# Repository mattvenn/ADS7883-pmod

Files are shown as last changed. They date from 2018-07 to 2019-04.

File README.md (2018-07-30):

# PMOD 2 x ADS7883 ADC

the ADS7883 is a 12 bit, serial ADC. It can sample up to 3MHz, and can be supplied up to 5v.

It needs 3 pins to operate: clk, select and data.

Supply can be 3.3v from the PMOD (limits maximum range of ADC to 3.3v), or 5v with a 
precision regulator and an external supply between 5.5v and 16v.

Use the ext/pmod jumper to select the source.

schematic

board

# Gerbers

## [fab-ADS7883-pmod-2018-07-02.zip](fab-ADS7883-pmod-2018-07-02.zip)

The silkscreen has an error on the 2 inputs. The 0v and ADC inputs are reversed. Attach 0v to ADC and ADC input to 0v.

## [fab-ADS7883-pmod-2018-07-30.zip](fab-ADS7883-pmod-2018-07-30.zip)

Fixes the reversed input labels.

# BOM

If you are using PMOD 3.3v for supply, you don't need C7, U1, C5.

LED D1 and R2 are optional for indicating PSU is good.

C1 to C4 are bypass caps and will help to improve noise performance if added.

* ADC1 and 2: ADS7883 http://es.farnell.com/texas-instruments/ads7883sbdbvt/adc-sar-12bit-3msps-6sot23/dp/2082426
* U1: ref5050 http://es.farnell.com/texas-instruments/ref5050aidg4/ref-de-tensi-n-serie-5v-soic-8/dp/1439628

# Verilog Core

[icestick/adc.v](adc.v) is tested Verilog for the ADC.

A working demo for the icestick is provided in the [icestick](icestick) directory. This reads ADC1 and shows top 5 bits on the icestick's LEDs.

To synthesise and program an attached icestick using the Icestorm tools:

    make prog

To simulate using iverilog and launch gtkwave to view the waveforms:

    make debug-adc

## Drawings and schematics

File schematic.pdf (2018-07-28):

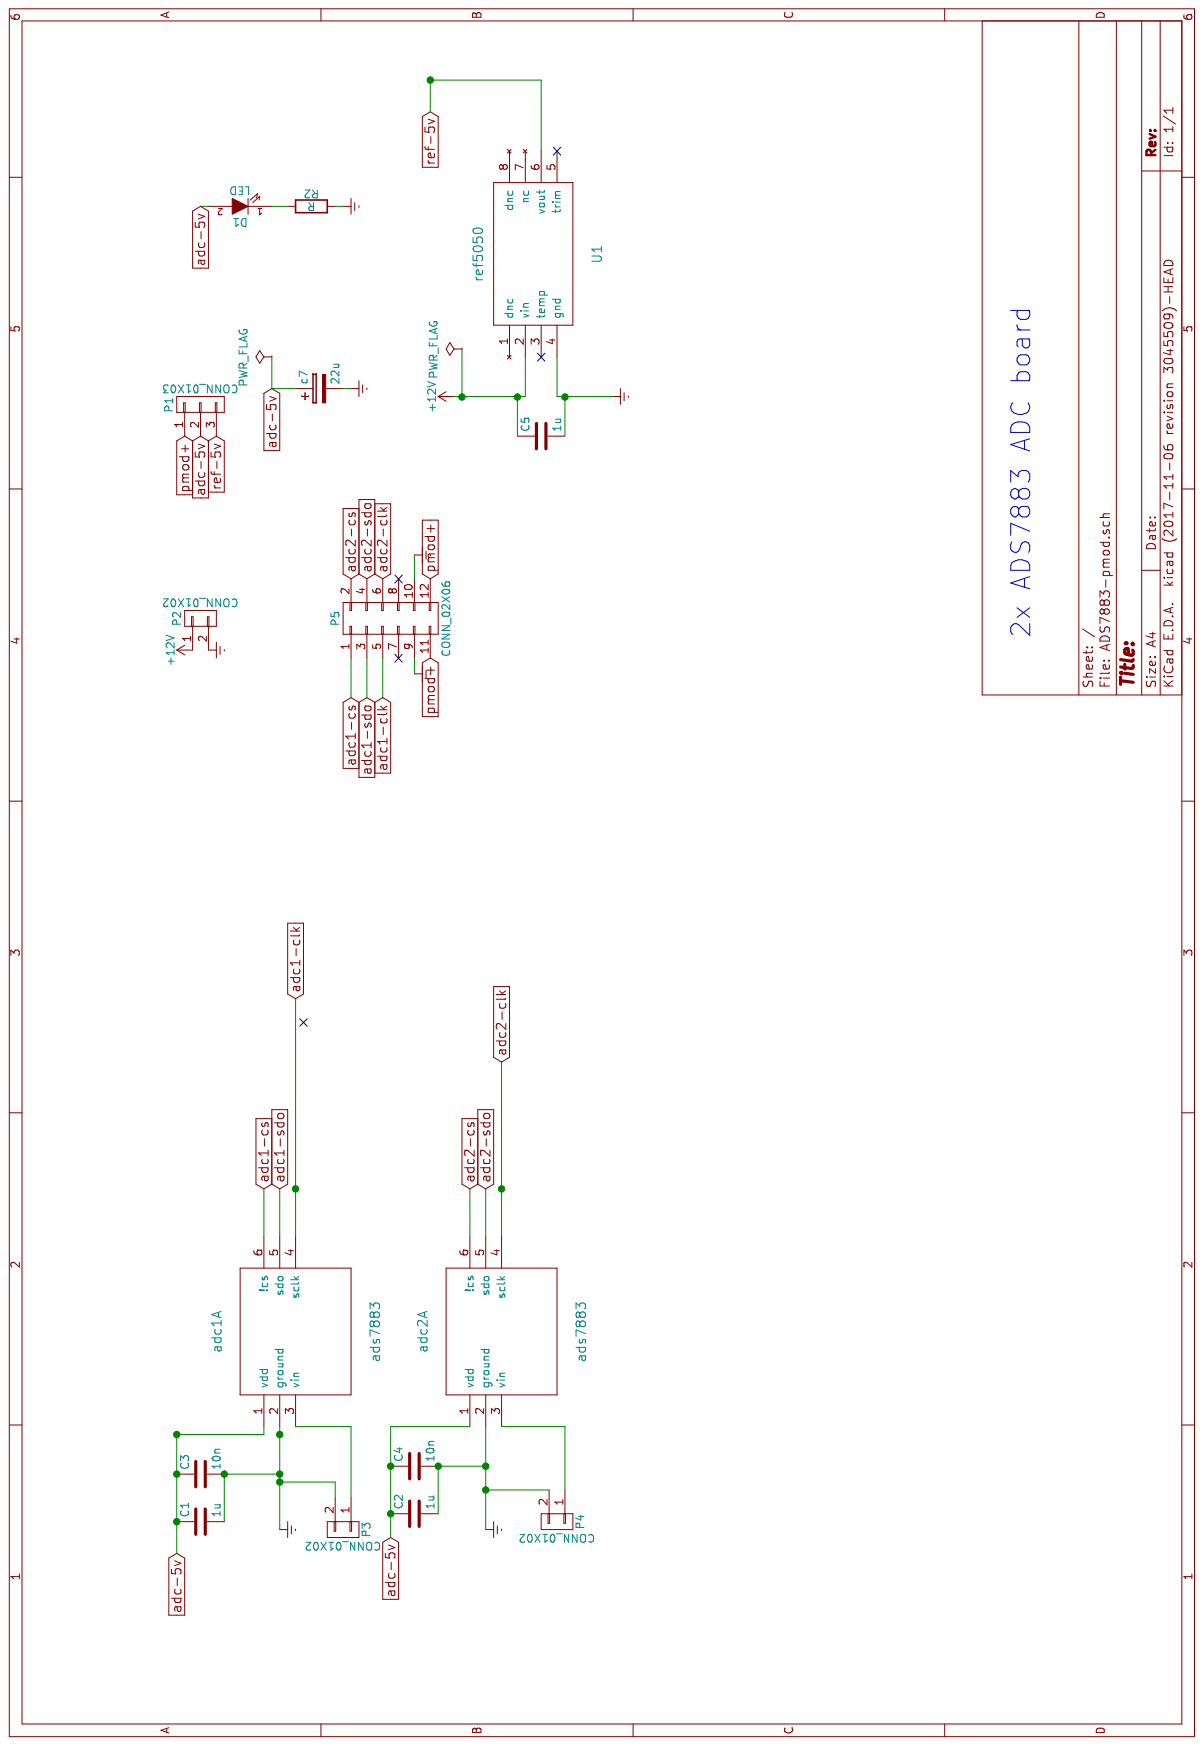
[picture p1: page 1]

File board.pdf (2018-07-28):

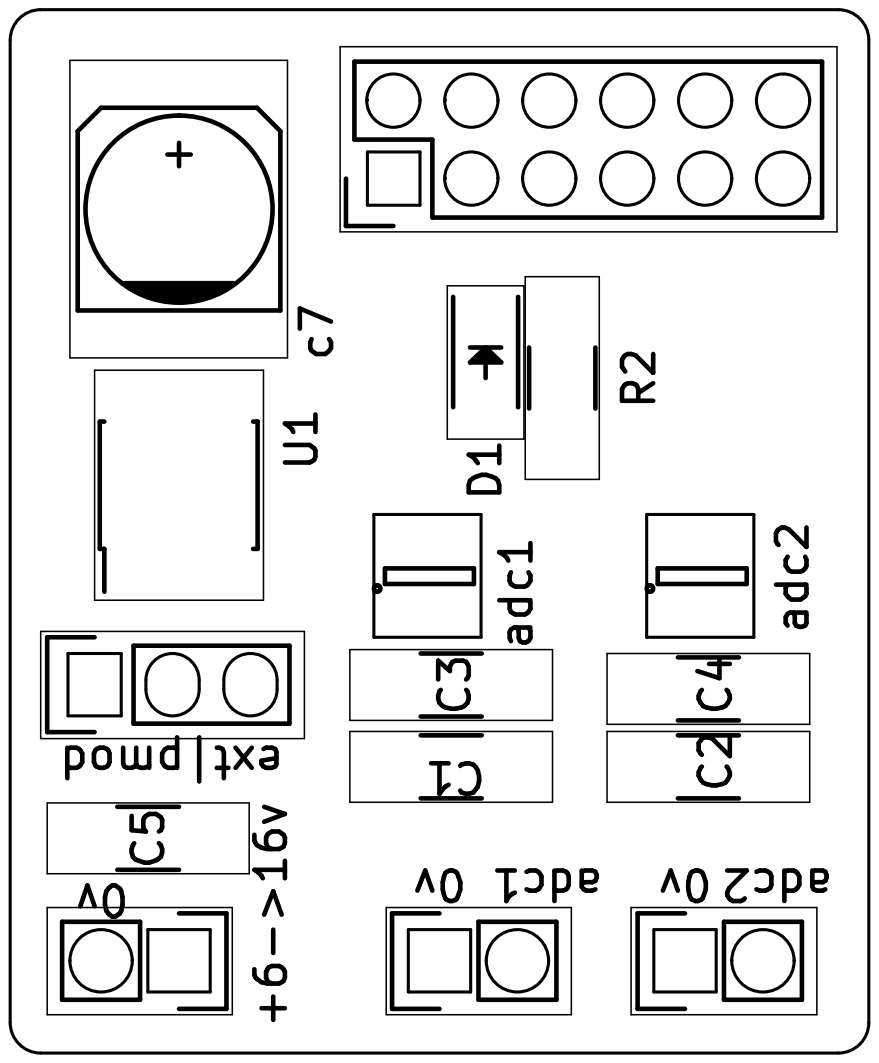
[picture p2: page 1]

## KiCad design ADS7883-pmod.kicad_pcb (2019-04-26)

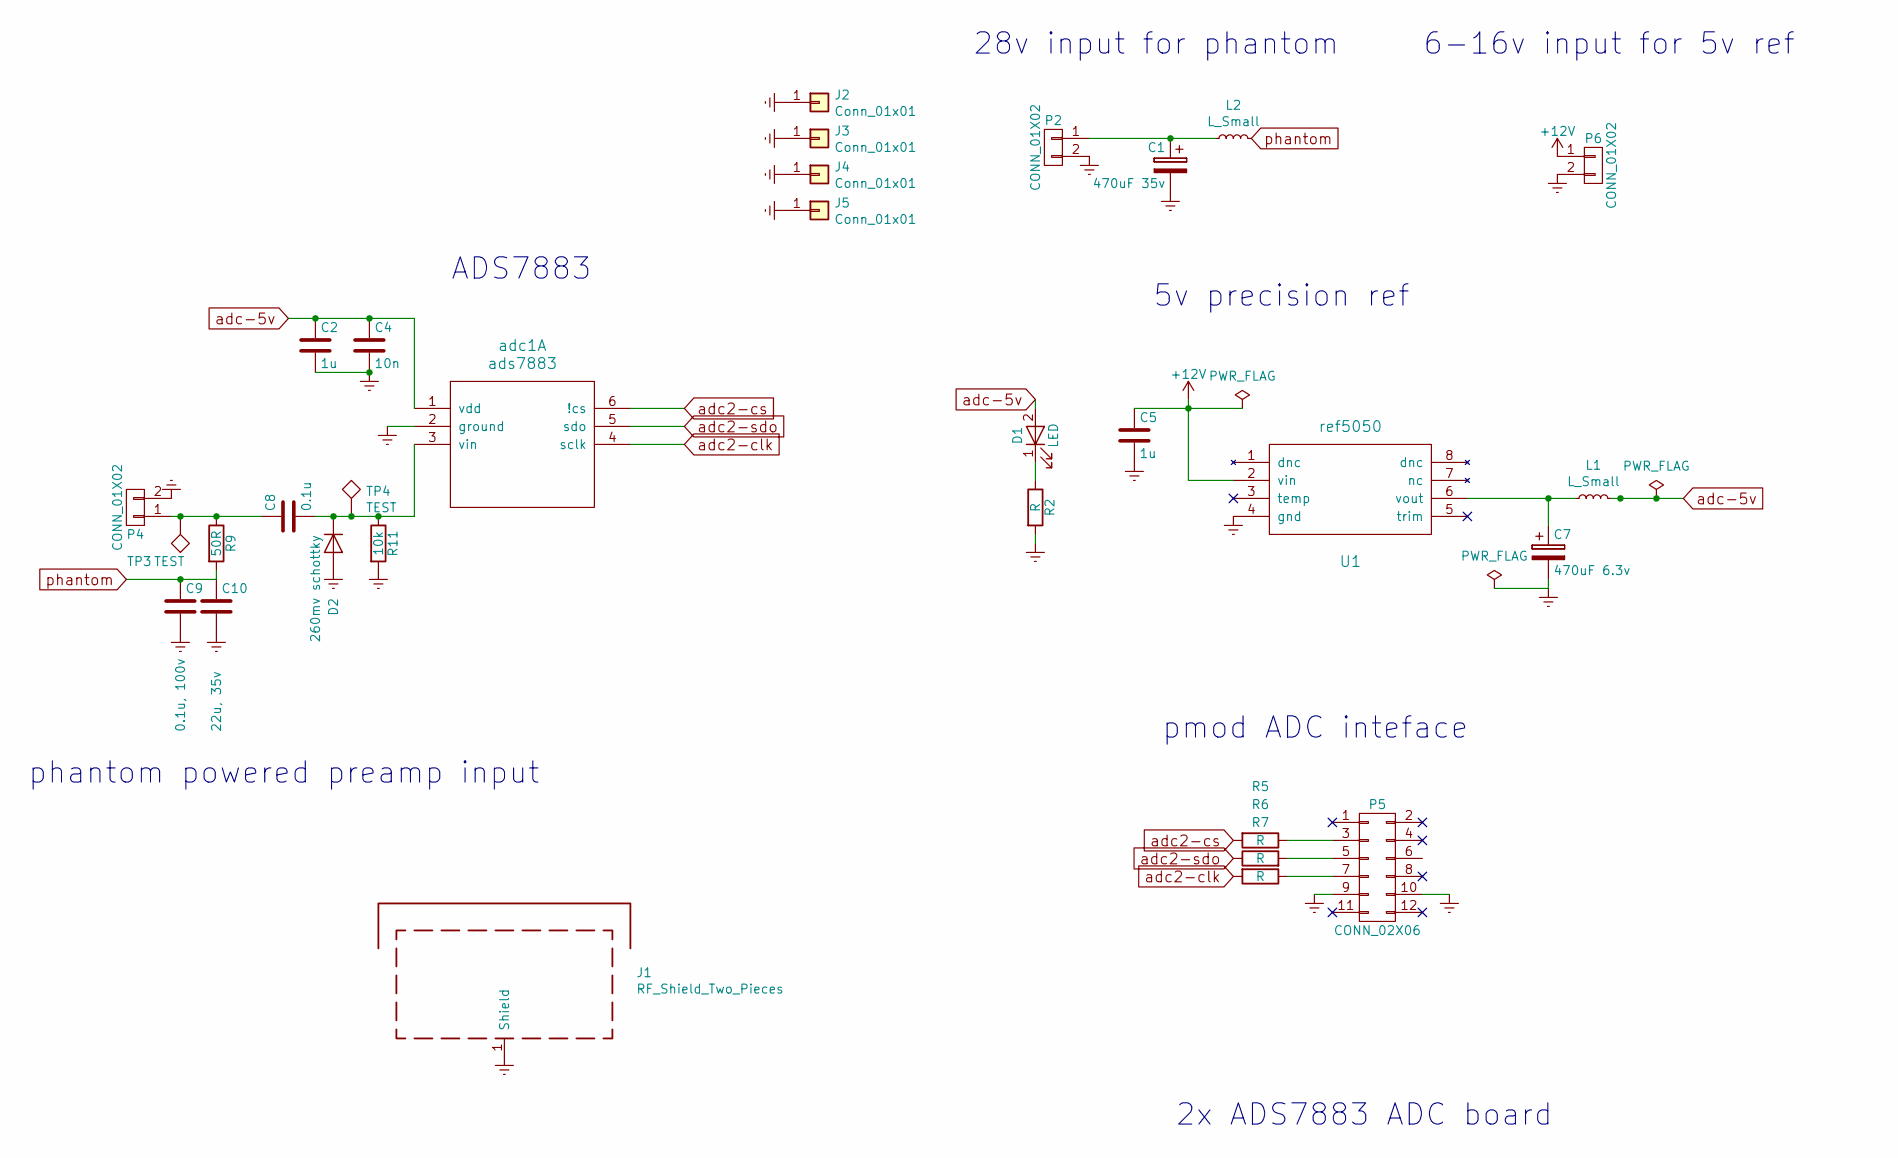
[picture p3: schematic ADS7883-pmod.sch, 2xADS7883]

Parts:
C1: 470uF 35v; CP_Elec_10x10; farnell # 2507737
C2, C5: 1u; C_0603_HandSoldering
C4: 10n; C_0603_HandSoldering
C7: 470uF 6.3v; CP_Elec_6.3x7.7; farnell # 2065955
C8: 0.1u; C_0603_HandSoldering
C9: 0.1u, 100v; C_0603_HandSoldering
C10: 22u, 35v; CP_Tantalum_Case-D_EIA-7343-31_Hand; farnell # 1457504
D1: LED; LED_0603_HandSoldering
D2: 260mv schottky; D_SOT-23_ANK; farnell # 1081206
J1: RF_Shield_Two_Pieces; Laird_Technologies_BMI-S-102_16.50x16.50mm; farnell # 2497717
J2, J3, J4, J5: Conn_01x01; MountingHole_3.2mm_M3_DIN965_Pad
L1, L2: L_Small; L_0603_HandSoldering
P2, P6: CONN_01X02; Pin_Header_Straight_1x02
P4: CONN_01X02; CON-SMA-EDGE
P5: CONN_02X06; Pin_Header_Straight_2x06
R2, R5, R6, R7: R; C_0603_HandSoldering
R9: 50R; R_1206_HandSoldering
R11: 10k; C_0603_HandSoldering
TP3, TP4: TEST; Test_Point_Pad_1.0x1.0mm
U1: ref5050; SOIC-8_3.9x4.9mm_Pitch1.27mm; farnell # 1439628
adc1: ads7883; SOT-23-6; farnell # 2082426

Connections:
+12V: C5.1, P6.1, U1.2 (vin)
Earth: C1.2, C2.2, C4.2, C5.2, C7.2, C9.2, C10.2, D2.2 (A), J1.1, J2.1, J3.1, J4.1, J5.1, P2.2, P4.2, P5.9, P5.10, P6.2, R2.2, R11.2, U1.4 (gnd), adc1.2 (ground)
unnamed: C1.1, L2.2, P2.1
unnamed: C7.1, L1.1, U1.6 (vout)
unnamed: C8.1, P4.1, R9.1, TP3.1
unnamed: C8.2, D2.1 (K), R11.1, TP4.1, adc1.3 (vin)
unnamed: D1.1 (K), R2.1
unnamed: P5.3, R5.1
unnamed: P5.5, R6.2
unnamed: P5.7, R7.1
adc2-clk: R7.2, adc1.4 (sclk)
adc2-cs: R5.2, adc1.6 (!cs)
adc2-sdo: R6.1, adc1.5 (sdo)
adc-5v: C2.1, C4.1, D1.2 (A), L1.2, adc1.1 (vdd)
phantom: C9.1, C10.1, L2.1, R9.2

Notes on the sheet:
2x ADS7883 ADC board
28v input for phantom
6-16v input for 5v ref
5v precision ref
pmod ADC inteface
ADS7883
phantom powered preamp input

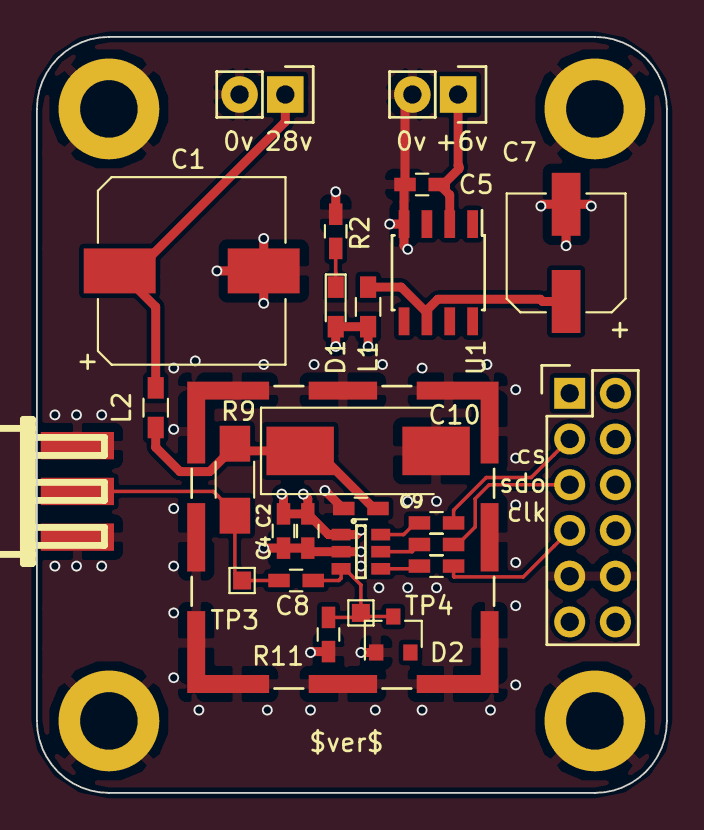
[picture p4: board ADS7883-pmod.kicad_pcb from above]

Board: 4 copper layers, 35.0 x 42.0 mm, 31 parts (0 on the bottom side), 15 nets.

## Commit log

2018-07-02 ads7883 pmod breakout first commit
    [ADS7883-pmod.kicad_pcb, ADS7883-pmod.sch]
2018-07-28 fix board for printing
    [ADS7883-pmod.kicad_pcb]
2018-07-28 updated docs
    [ADS7883-pmod.kicad_pcb, ADS7883-pmod.sch]
2018-07-30 fix reverse input labels
    [ADS7883-pmod.kicad_pcb]
2019-04-25 convert to 4 layers and improve routing
    [ADS7883-pmod.kicad_pcb, ADS7883-pmod.sch]
2019-04-26 got rid of 1 ADC and added phantom and shield can
    [ADS7883-pmod.kicad_pcb, ADS7883-pmod.sch]
